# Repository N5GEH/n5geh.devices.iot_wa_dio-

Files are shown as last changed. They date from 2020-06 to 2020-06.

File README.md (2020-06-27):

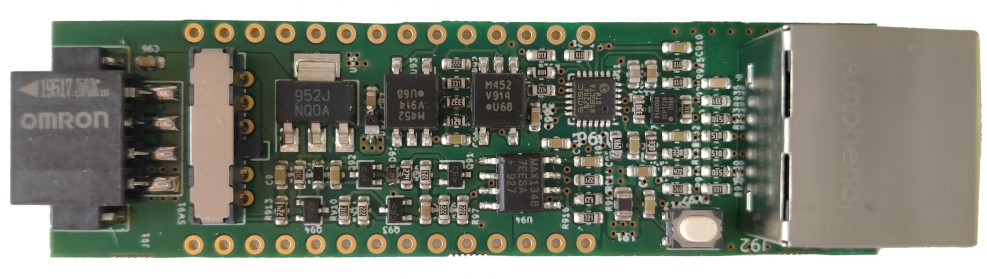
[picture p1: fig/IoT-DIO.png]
#   IoT-DIO <br/> Digital IO IoT Wireless Adapter

IoT-DIO is a wireless adapter for developing IoT applications for Industrial and Building Automation Systems based on the Espressif chipset ESP32. The adapter is compatible with:
- RS485
- M-Bus
- Ethernet

The library allows the implemention of IoT applications that rely on MQTT protocol via WiFi/NB-IoT/LTE Cat-M1 interfaces.

## Adapter versions
The Iot-DIO wireless adapter is available in two versions developed using [KiCAD 5.1](https://kicad-pcb.org/) and compatible with:
- [ESP32-PICO-KIT v4](https://docs.espressif.com/projects/esp-idf/en/latest/esp32/hw-reference/esp32/get-started-pico-kit.html) - is an ESP32-based mini development board produced by [Espressif](https://espressif.com/). The board features integrated Wifi and BLE capabilites.
- [FiPy](https://pycom.io/product/fipy/) - is an ESP32-based mini development board produced by [Pycom](https://pycom.io/). The board features integrated Wifi, BLE, LoRa, Sigfox, NB-IoT and LTE Cat-M1 capabilities.

## Development Framework
IoT-DIO relies on the Espressif IoT Development Framework [ESP-IDF](https://github.com/espressif/esp-idf), the official development framework for the [ESP32](https://espressif.com/en/products/hardware/esp32/overview) chip.

## Configuration
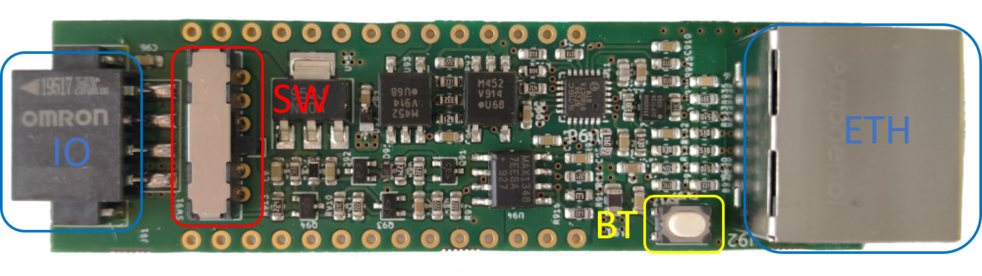
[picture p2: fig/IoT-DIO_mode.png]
IoT-DIO Mode


### Pinout
IO pinout (top-down):
- 0: V_BUS
- 1: M-/B-
- 2: M+/A+
- 3: GND

### Functions button
The push button BT performs multiple operations depending on the pressure time Tp.

| Pressure Time | Action |
|:---:|:---|
| Tp < 1s | Performs a soft-reset of the adapter |
|1s < Tp < 5s | Enables the AP mode. If not previously changed, the device will be visible by default with the SSID `ESP_<MAC>`, where <MAC> is the MAC address of the adapter network interface in hex format|
|5s < Tp | Performs a hard-reset of the adapter deleting the previously stored configuration|

# Publications

We kindly ask academic publications employing based or inspired to IoT-AIO to cite at least one of the following papers:

- M.H. Schraven, C. Guarnieri Calò Carducci, M.A. Baranski, D. Mueller, A. Monti, “Designing a Development Board for Research on IoT Appli-cations in Building Automation Systems,” 36th International Symposiumon  Automation  and  Robotics  in  Construction  (ISARC  2019),  Banff,Canada, 2019, pp. 82-90, [DOI: 10.22260/ISARC2019/0012](https://doi.org/10.22260/ISARC2019/0012)
- C. Guarnieri Calò Carducci, A. Monti, M. H. Schraven, M. Schumacher and D. Mueller, “Enabling ESP32-based IoT Applications in Building Automation Systems,” 2019 II Workshop on Metrology for Industry 4.0 and IoT (MetroInd4.0&IoT), Naples, Italy, 2019, pp. 306-311, [DOI: 10.1109/METROI4.2019.8792852](https://doi.org/10.1109/METROI4.2019.8792852)

# Copyright

2019-2020, Institute for Automation of Complex Power Systems, EONERC  

# License

<br />This work is licensed under a <a rel="license" href="http://creativecommons.org/licenses/by/4.0/">Creative Commons Attribution 4.0 International License</a>.

# Contact
EONERC ACS Logo (http://www.acs.eonerc.rwth-aachen.de)

- [Carlo Guarnieri Calò Carducci (PhD)](mailto:cguarnieri@eonerc.rwth-aachen.de)

[Institute for Automation of Complex Power Systems (ACS)](http://www.acs.eonerc.rwth-aachen.de)  
[EON Energy Research Center (EONERC)](http://www.eonerc.rwth-aachen.de)  
[RWTH University Aachen, Germany](http://www.rwth-aachen.de)

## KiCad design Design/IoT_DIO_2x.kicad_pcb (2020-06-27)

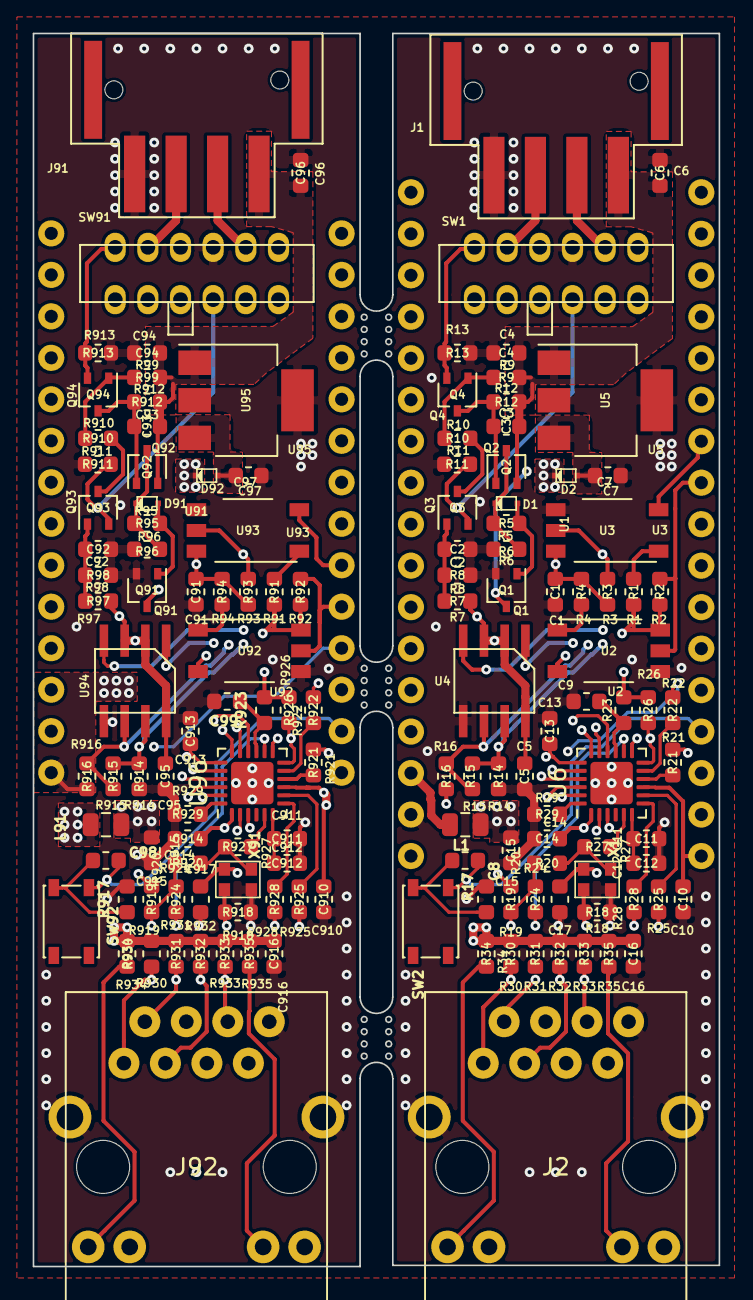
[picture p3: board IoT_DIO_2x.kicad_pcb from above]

Board: 4 copper layers, 42.0 x 75.5 mm, 140 parts (0 on the bottom side), 109 nets.

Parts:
C1, C3, C5, C7, C8, C9, C10, C13, C14, C17, C91, C93, C95, C97, C98, C99, C910, C913, C914, C917: 100n; C_0603_1608Metric
C2, C12, C92, C912: 1u; C_0603_1608Metric
C4, C94: 10u; C_0603_1608Metric
C6, C96: 220n; C_0603_1608Metric
C11, C911: 470p; C_0603_1608Metric
C15, C915: 4.7u; C_0603_1608Metric
C16, C916: 22n; C_0603_1608Metric
D1, D2, D91, D92: D_Schottky BAS52-02V; BAS52
J1, J91: Conn_01x04 XW4L-04A1-H1; XW4L-04A1-H1
J2, J92: RJ45_LED_Shielded; HR911105A
L1, L91: BK2125HS470-T; L_0805_2012Metric
Q1, Q3, Q4, Q91, Q93, Q94: BC817-40WT1G; SOT-323_SC-70
Q2, Q92: BC857BWT1G; SOT-323_SC-70
R1, R34, R35, R91, R934, R935: 330; R_0603_1608Metric
R2, R7, R8, R11, R26, R92, R97, R98, R911, R926: 2.2k; R_0603_1608Metric
R3, R93: 3.3k; R_0603_1608Metric
R4, R94: 620; R_0603_1608Metric
R5, R13, R95, R913: 220k; R_0603_1608Metric
R6, R96: 22k; R_0603_1608Metric
R9, R10, R17, R18, R99, R910, R917, R918: 10k; R_0603_1608Metric
R12, R912: 82; R_0603_1608Metric
R14, R16, R914, R916: 220; R_0603_1608Metric
R15, R915: 120; R_0603_1608Metric
R19, R23, R919, R923: 4.7k; R_0603_1608Metric
R20, R24, R27, R30, R31, R32, R33, R920, R924, R927, R930, R931, R932, R933: 49.9; R_0603_1608Metric
R21, R22, R25, R28, R921, R922, R925, R928: 10; R_0603_1608Metric
R29, R929: 12.1k; R_0603_1608Metric
SW1, SW91: MS42R
SW2, SW92: PTS810SJK250SMTRLFS; SW_SPST_PTS810
U1: ESP-32-PICO-KIT-V4; ESP32v4
U2, U3, U92, U93: VOM452T; MFSOP6-5_4.4x3.6mm_P1.27mm
U4, U94: MAX13487EESA+; MAX13487
U5, U95: LM340MP-5.0/NOPB; SOT-223-3_TabPin2
U6, U96: LAN8720A-CP; QFN-24-1EP_4x4mm_P0.5mm_EP2.6x2.6mm
U91: FiPy
X1, X91: DSC6011JI1A-050.0000; Oscillator_DSC60xx_Microchip-4Pin_2.5x2.0mm

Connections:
+3V3: C10.1, C17.1, C910.1, C917.1, L1.1, L91.1, R1.2, R2.1, R19.2, R21.2, R23.2, R26.2, R91.2, R92.1, R919.2, R921.2, R923.2, R926.2, U1.1, U1.32, U2.6, U6.9, U91.26, U92.6, U96.9, X1.4, X91.4
+5V: C1.1, C5.1, C91.1, C95.1, D2.1, D92.1, R3.2, R4.1, R7.1, R16.1, R93.2, R94.1, R97.1, R916.1, U1.34, U3.6, U4.2, U4.3, U4.8, U91.28, U93.6, U94.2, U94.3, U94.8
/IoT_DIO_ESP/Ethernet/CRS_DV: R22.2, U1.24
/IoT_DIO_ESP/Ethernet/LED1: J2.10, U6.3
/IoT_DIO_ESP/Ethernet/LED2: J2.12, U6.2
/IoT_DIO_ESP/Ethernet/MDC: U1.14, U6.13
/IoT_DIO_ESP/Ethernet/MDIO: R26.1, U1.13, U6.12
/IoT_DIO_ESP/Ethernet/PHY_POWER: R18.2, U1.26, X1.1
/IoT_DIO_ESP/Ethernet/RXD0: R25.2, U1.20
/IoT_DIO_ESP/Ethernet/RXD1: R28.2, U1.21
/IoT_DIO_ESP/Ethernet/R_RXCLK: R19.1, R20.2, R24.2, U1.31
/IoT_DIO_ESP/Ethernet/TXD0: U1.15, U6.17
/IoT_DIO_ESP/Ethernet/TXD1: U1.16, U6.18
/IoT_DIO_ESP/Ethernet/TX_EN: U1.17, U6.16
/IoT_DIO_ESP/Ethernet/nRST: C9.1, R23.1, U6.15
/IoT_DIO_ESP/MBUS/M+: Q4.2, R13.1, SW1.7
/IoT_DIO_ESP/RS485/A+: R15.1, R16.2, SW1.9, U4.6
/IoT_DIO_ESP/RS485/B-: R14.1, R15.2, SW1.12, U4.7
/IoT_DIO_ESP/Rx_Mbus: Q1.3, SW1.1
/IoT_DIO_ESP/Rx_RS485: SW1.3, U4.1
/IoT_DIO_ESP/Tx_Mbus: Q3.2, R11.1, SW1.4
/IoT_DIO_ESP/Tx_RS485: SW1.6, U4.4
/IoT_DIO_FyPy/Ethernet1/CRS_DV: R922.2, U91.8
/IoT_DIO_FyPy/Ethernet1/LED1: J92.10, U96.3
/IoT_DIO_FyPy/Ethernet1/LED2: J92.12, U96.2
/IoT_DIO_FyPy/Ethernet1/MDC: U91.20, U96.13
/IoT_DIO_FyPy/Ethernet1/MDIO: R926.1, U91.19, U96.12
/IoT_DIO_FyPy/Ethernet1/PHY_POWER: R918.2, U91.25, X91.1
/IoT_DIO_FyPy/Ethernet1/RXD0: R925.2, U91.24
/IoT_DIO_FyPy/Ethernet1/RXD1: R928.2, U91.23
/IoT_DIO_FyPy/Ethernet1/R_RXCLK: R919.1, R920.2, R924.2, U91.4
/IoT_DIO_FyPy/Ethernet1/TXD0: U91.9, U96.17
/IoT_DIO_FyPy/Ethernet1/TXD1: U91.13, U96.18
/IoT_DIO_FyPy/Ethernet1/TX_EN: U91.14, U96.16
/IoT_DIO_FyPy/Ethernet1/nRST: C99.1, R923.1, U96.15
/IoT_DIO_FyPy/MBUS/M+: Q94.2, R913.1, SW91.7
/IoT_DIO_FyPy/RS485/A+: R915.1, R916.2, SW91.9, U94.6
/IoT_DIO_FyPy/RS485/B-: R914.1, R915.2, SW91.12, U94.7
/IoT_DIO_FyPy/Rx_Mbus: Q91.3, SW91.1
/IoT_DIO_FyPy/Rx_RS485: SW91.3, U94.1
/IoT_DIO_FyPy/Tx_Mbus: Q93.2, R911.1, SW91.4
/IoT_DIO_FyPy/Tx_RS485: SW91.6, U94.4
GND: C1.2, C2.2, C4.2, C5.2, C6.2, C7.2, C9.2, C10.2, C11.2, C12.2, C13.2, C14.2, C15.2, C16.2, C17.2, C91.2, C92.2, C94.2, C95.2, C96.2, C97.2, C99.2, C910.2, C911.2, C912.2, C913.2, C914.2, C915.2, C916.2, C917.2, J1.4, J2.8, J2.13, J2.14, J91.4, J92.8, J92.13, J92.14, Q1.2, Q91.2, R6.2, R8.2, R11.2, R13.2, R14.2, R17.2, R18.1, R29.1, R96.2, R98.2, R911.2, R913.2, R914.2, R917.2, R918.1, R929.1, SW1.10, SW91.10, U1.2, U1.33, U2.4, U3.4, U4.5, U5.2, U6.25, U91.27, U92.4, U93.4, U94.5, U95.2, U96.25, X1.2, X91.2
unnamed: C2.1, Q3.1, R7.2, R8.1
unnamed: C3.2, Q2.1, Q4.3, R12.2
unnamed: C7.1, D2.2, U5.3
unnamed: C8.1, SW2.4, U1.4
unnamed: C8.2, R17.1, SW2.2
unnamed: C11.1, C12.1, U6.6
unnamed: C92.1, Q93.1, R97.2, R98.1
unnamed: C93.2, Q92.1, Q94.3, R912.2
unnamed: C97.1, D92.2, U95.3
unnamed: C98.1, SW92.4, U91.2
unnamed: C98.2, R917.1, SW92.2
unnamed: C911.1, C912.1, U96.6
unnamed: D1.1, Q2.3, R5.1, R6.1
unnamed: D1.2, Q1.1, R5.2
unnamed: D91.1, Q92.3, R95.1, R96.1
unnamed: D91.2, Q91.1, R95.2
unnamed: J1.2, SW1.11
unnamed: J1.3, SW1.8
unnamed: J2.1, R30.1, U6.21
unnamed: J2.2, R31.1, U6.20
unnamed: J2.3, R32.1, U6.23
unnamed: J2.6, R33.1, U6.22
unnamed: J2.9, R34.1
unnamed: J2.11, R35.1
unnamed: J91.2, SW91.11
unnamed: J91.3, SW91.8
unnamed: J92.1, R930.1, U96.21
unnamed: J92.2, R931.1, U96.20
unnamed: J92.3, R932.1, U96.23
unnamed: J92.6, R933.1, U96.22
unnamed: J92.9, R934.1
unnamed: J92.11, R935.1
unnamed: Q3.3, R10.2
unnamed: Q4.1, R9.2, R10.1
unnamed: Q93.3, R910.2
unnamed: Q94.1, R99.2, R910.1
unnamed: R1.1, U3.1
unnamed: R2.2, U1.10, U2.5
unnamed: R3.1, SW1.5, U3.5
unnamed: R4.2, U2.1
unnamed: R20.1, R27.2, X1.3
unnamed: R21.1, U6.10
unnamed: R22.1, U6.11
unnamed: R24.1, U6.14
unnamed: R25.1, U6.8
unnamed: R27.1, U6.5
unnamed: R28.1, U6.7
unnamed: R29.2, U6.24
unnamed: R91.1, U93.1
unnamed: R92.2, U91.5, U92.5
unnamed: R93.1, SW91.5, U93.5
unnamed: R94.2, U92.1
unnamed: R920.1, R927.2, X91.3
unnamed: R921.1, U96.10
unnamed: R922.1, U96.11
unnamed: R924.1, U96.14
unnamed: R925.1, U96.8
unnamed: R927.1, U96.5
unnamed: R928.1, U96.7
unnamed: R929.2, U96.24
unnamed: SW1.2, U2.3
unnamed: SW91.2, U92.3
unnamed: U1.11, U3.3
unnamed: U91.6, U93.3
VBUS: C3.1, C4.1, C6.1, C93.1, C94.1, C96.1, J1.1, J91.1, Q2.2, Q92.2, R9.1, R12.1, R99.1, R912.1, U5.1, U95.1
VDDA: C13.1, C14.1, C15.1, C16.1, C913.1, C914.1, C915.1, C916.1, J2.4, J2.5, J92.4, J92.5, L1.2, L91.2, R30.2, R31.2, R32.2, R33.2, R34.2, R35.2, R930.2, R931.2, R932.2, R933.2, R934.2, R935.2, U6.1, U6.19, U96.1, U96.19
